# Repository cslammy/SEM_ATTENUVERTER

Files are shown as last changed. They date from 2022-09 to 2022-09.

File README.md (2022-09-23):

# SEM_ATTENUVERTER
Audio Attenuverter inspired by classic Tom Oberheim designs

My First experience with an attenuverter--turn a pot CCW, you get increasing amplitude and a signal in phase; CW and you get increasing amplitude with the signal 180 degrees out of phase, was the filter mod pots found an Oberheim SEM. Was I 14 years old? Well, it blew my young mind....Combined with the SEMs multimode filter you can get all sorts of cool sound with the attenuator/inverter + filter, but now, with attenuverters found everywhere, they are, well, everywhere.  This time I used the same core component that made the SEM attenuverter so cool, the somewhat unusual (but not unobtainium) center tapped pot as module's the centerpiece.  Homage to the mighty TO! At noon you get ground--zilch. Turn the pot and you get attenuverter action.  I also added bias offset for each signal, controllable by CV or a set 5V signal. This is an evolving design....it is for +/- 15V "large format" or Frac, but a +/- 12V Euro redesign in is the works.

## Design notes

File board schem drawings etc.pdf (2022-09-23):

# MAw BOARD

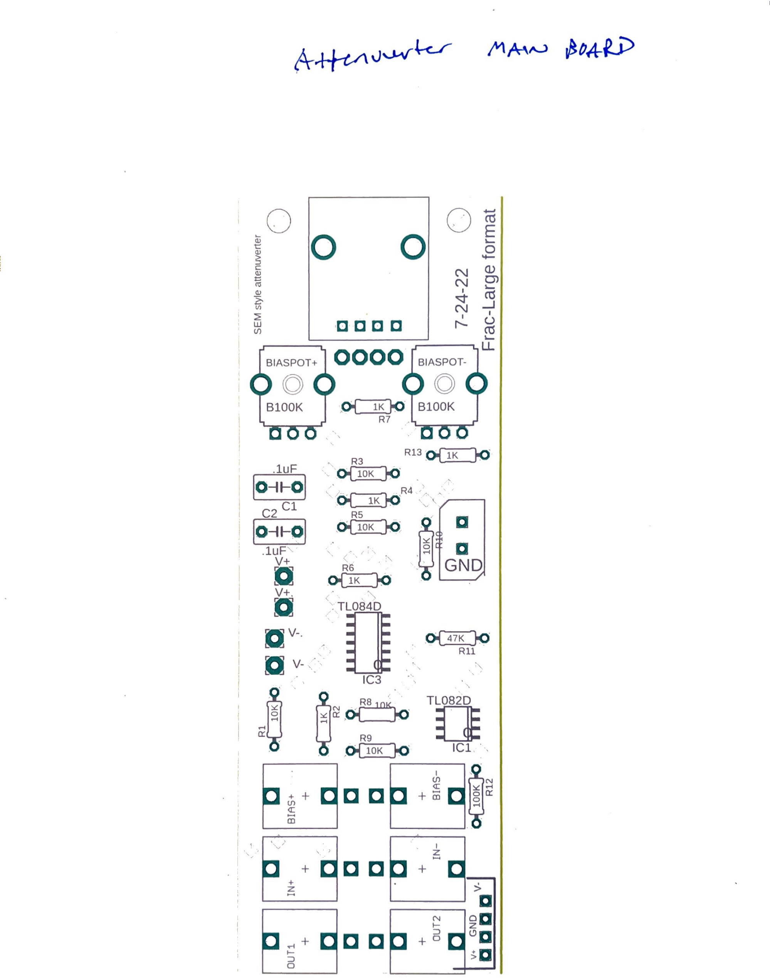
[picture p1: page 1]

3

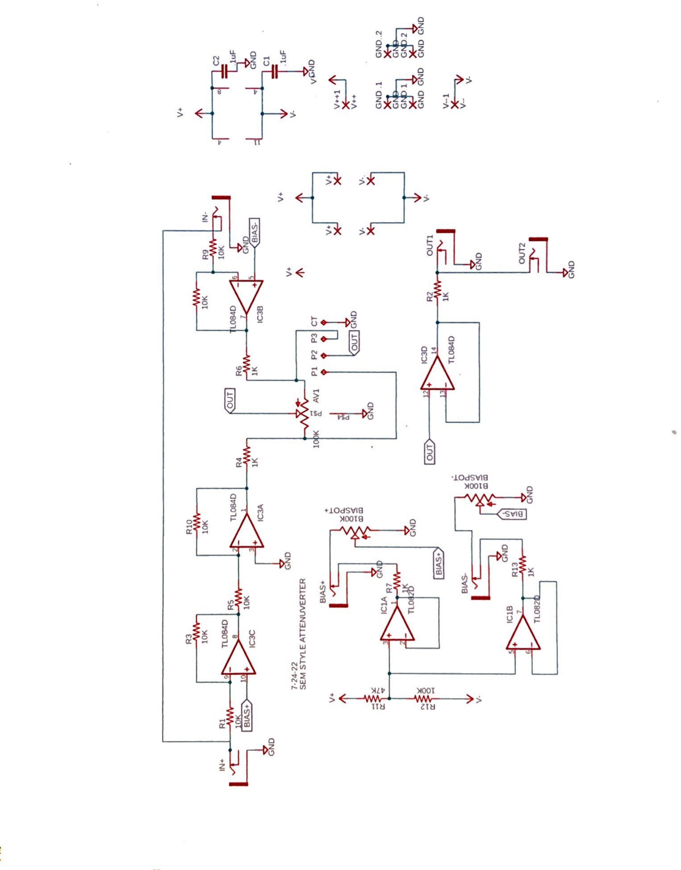
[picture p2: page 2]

f | . | "

?LOdSvIa
OOTE

I-A

ea

v
Tota

Tt

+1LOdsvid
OOTS:

# prerw ete ev pat

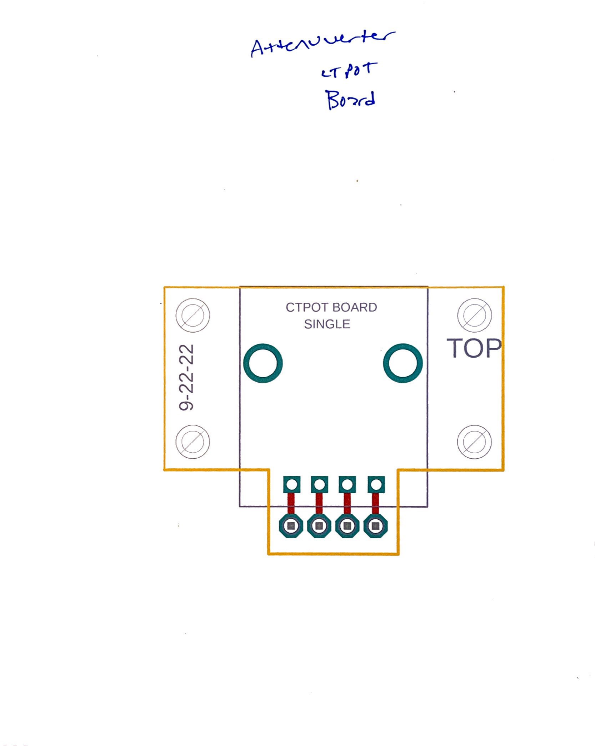
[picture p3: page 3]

# Bord

# CTPOT BOARD SINGLE

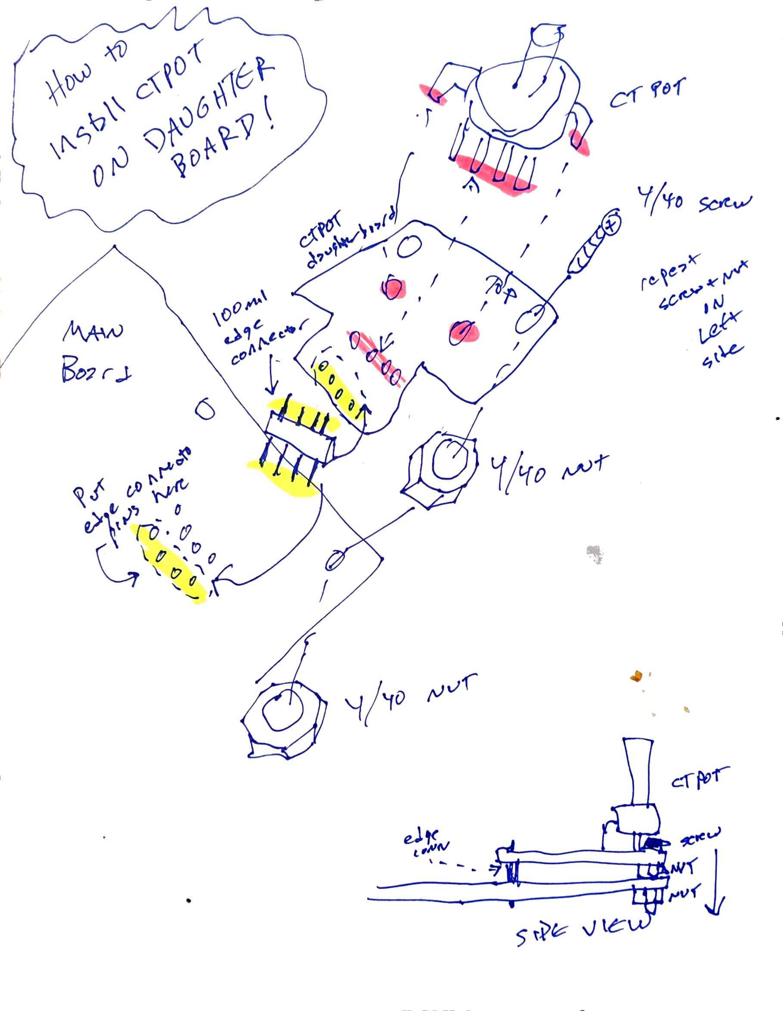
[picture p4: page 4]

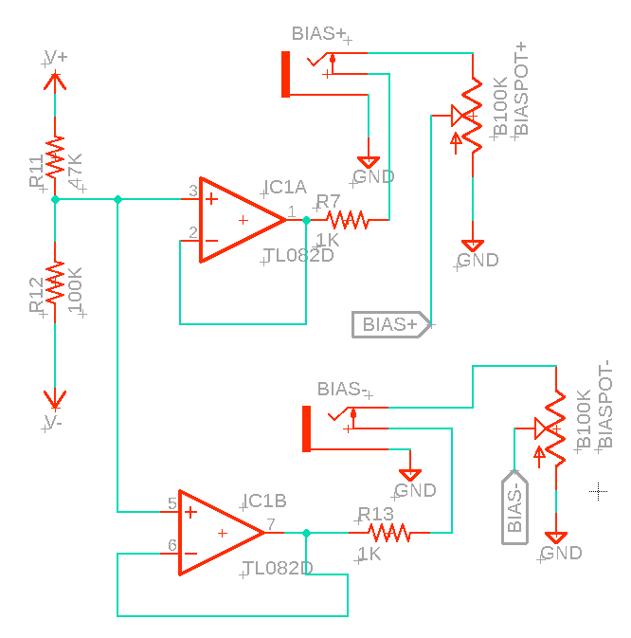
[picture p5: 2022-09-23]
inputaftermod.PNG

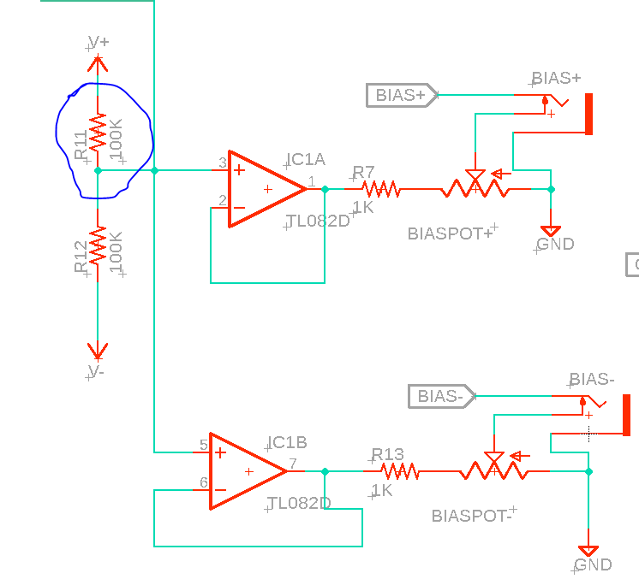
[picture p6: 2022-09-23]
beforebiasinput_mod.PNG

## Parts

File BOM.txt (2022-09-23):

BOM Large Format/Frac SEM style attenuverter

Part     Value         Device           Package         Description                                                                                                
AV1      100K          ALPSRK11K114     ALPSCENTERTAP   ALPS Pot with center tap ground                                                                                                                   
BIAS+    THONKICONNOLD THONKICONNOLD    THONKICONN      3.5mm socket for Eurorack modular synths                                                                                                          
BIAS-    THONKICONNOLD THONKICONNOLD    THONKICONN      3.5mm socket for Eurorack modular synths                                                                                                          
BIASPOT+ B100K         9MM_SNAP-IN_POT_ 9MM_SNAP-IN_POT "Tall Trimmer"  search on thonk.com                                                                                                
BIASPOT- B100K         9MM_SNAP-IN_POT_ 9MM_SNAP-IN_POT "Tall Trimmer"                                                                                                 
C1       .1uF          C5/3.5           C5B3.5          CAPACITOR                                                                                                                                         
C2       .1uF          C5/3.5           C5B3.5          CAPACITOR                                                                                                                                         
                                                                                                                                  
IC1      TL082D        TL082D           SO08            OP AMP                                                                        
IC3      TL084D        TL084D           SO14            OP AMP                                                                                                                                            
IN+      THONKICONNOLD THONKICONNOLD    THONKICONN      3.5mm socket for Eurorack modular synths                                                                                                          
IN-      THONKICONNOLD THONKICONNOLD    THONKICONN      3.5mm socket for Eurorack modular synths                                                                                                          
OUT1     THONKICONNOLD THONKICONNOLD    THONKICONN      3.5mm socket for Eurorack modular synths                                                                                                          
OUT2     THONKICONNOLD THONKICONNOLD    THONKICONN      3.5mm socket for Eurorack modular synths                                                                                                          
P1       TPPAD1-13     TPPAD1-13        P1-13           Test pad NO NAME                                                                                                                                  
P2       TPPAD1-13     TPPAD1-13        P1-13           Test pad NO NAME                                                                                                                                  
P3       TPPAD1-13     TPPAD1-13        P1-13           Test pad NO NAME                                                                                                                                  
R1       10K           R-US_0204/7      0204/7          RESISTOR, American symbol                                                                                                                         
R2       1K            R-US_0204/7      0204/7          RESISTOR, American symbol                                                                                                                         
R3       10K           R-US_0204/7      0204/7          RESISTOR, American symbol                                                                                                                         
R4       1K            R-US_0204/7      0204/7          RESISTOR, American symbol                                                                                                                         
R5       10K           R-US_0204/7      0204/7          RESISTOR, American symbol                                                                                                                         
R6       1K            R-US_0204/7      0204/7          RESISTOR, American symbol                                                                                                                         
R7       1K            R-US_0204/7      0204/7          RESISTOR, American symbol                                                                                                                         
R8       10K           R-US_0204/7      0204/7          RESISTOR, American symbol                                                                                                                         
R9       10K           R-US_0204/7      0204/7          RESISTOR, American symbol                                                                                                                         
R10      10K           R-US_0204/7      0204/7          RESISTOR, American symbol                                                                                                                         
R11      47K           R-US_0204/7      0204/7          RESISTOR, American symbol                                                                                                                         
R12      100K          R-US_0204/7      0204/7          RESISTOR, American symbol                                                                                                                         
R13      1K            R-US_0204/7      0204/7          RESISTOR, American symbol

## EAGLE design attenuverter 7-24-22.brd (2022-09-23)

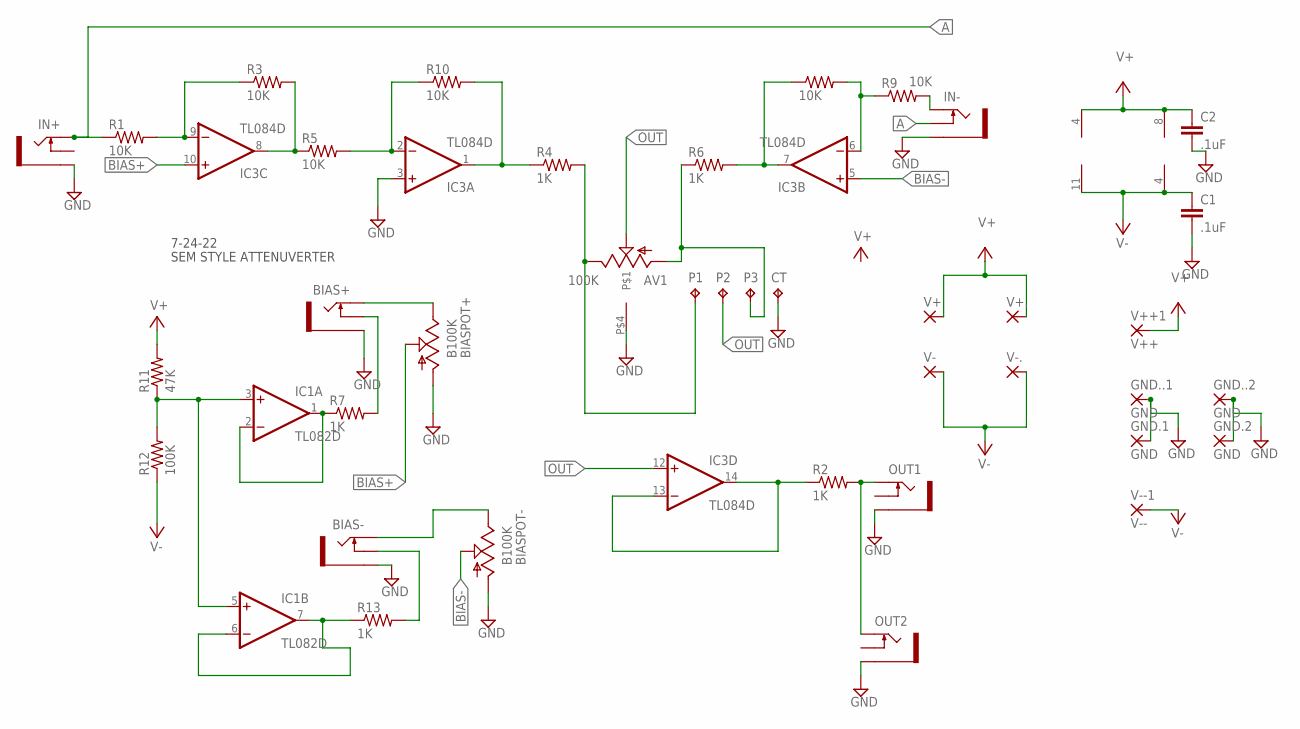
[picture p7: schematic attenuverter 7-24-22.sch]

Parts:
AV1: 100K; ALPSCENTERTAP
BIAS+: THONKICONNOLD; THONKICONN
BIAS-: THONKICONNOLD; THONKICONN
BIASPOT+: B100K; 9MM_SNAP-IN_POT
BIASPOT-: B100K; 9MM_SNAP-IN_POT
C1, C2: .1uF; C5B3.5
CT: TPPAD1-13; P1-13
GND.1, GND.2, GND..1, GND..2: GND; 1,6/0,8
IC1: TL082D; SO08
IC3: TL084D; SO14
IN+: THONKICONNOLD; THONKICONN
IN-: THONKICONNOLD; THONKICONN
OUT1, OUT2: THONKICONNOLD; THONKICONN
P1, P2, P3: TPPAD1-13; P1-13
R1, R3, R5, R8, R9, R10: 10K; 0204/7
R2, R4, R6, R7, R13: 1K; 0204/7
R11: 47K; 0204/7
R12: 100K; 0204/7
V+, V+.: WIREPAD2,54/1,1; 2,54/1,1
V++1: V++; 1,6/0,8
V-, V-.: WIREPAD2,54/1,1; 2,54/1,1
V--1: V--; 1,6/0,8

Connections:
A: IN+.P$3_TIP (TIP), IN-.P$2_SWITCH (SWITCH), R1.1
BIAS+: BIASPOT+.2 (S), IC3.10 (+IN)
BIAS-: BIASPOT-.2 (S), IC3.5 (+IN)
GND: AV1.P$4, BIAS+.P$1_SLEEVE (SLEEVE), BIAS-.P$1_SLEEVE (SLEEVE), BIASPOT+.1 (A), BIASPOT-.1 (A), C1.2, C2.2, CT.TP, GND.1.1, GND.2.1, GND..1.1, GND..2.1, IC3.3 (+IN), IN+.P$1_SLEEVE (SLEEVE), IN-.P$1_SLEEVE (SLEEVE), OUT1.P$1_SLEEVE (SLEEVE), OUT2.P$1_SLEEVE (SLEEVE)
unnamed: IC3.6 (-IN), R8.2, R9.1
unnamed: IC1.3 (+IN), IC1.5 (+IN), R11.1, R12.2
unnamed: IC3.7 (OUT), R6.2, R8.1
unnamed: IC1.1 (OUT), IC1.2 (-IN), R7.1
unnamed: AV1.P$1 (HIGH), P1.TP, R4.2
unnamed: IC1.6 (-IN), IC1.7 (OUT), R13.1
unnamed: BIAS-.P$3_TIP (TIP), BIASPOT-.3 (E)
unnamed: IN-.P$3_TIP (TIP), R9.2
unnamed: BIAS+.P$2_SWITCH (SWITCH), R7.2
unnamed: BIAS-.P$2_SWITCH (SWITCH), R13.2
unnamed: IC3.9 (-IN), R1.2, R3.1
unnamed: IC3.13 (-IN), IC3.14 (OUT), R2.1
unnamed: AV1.P$3 (LOW), P3.TP, R6.1
unnamed: BIAS+.P$3_TIP (TIP), BIASPOT+.3 (E)
unnamed: IC3.8 (OUT), R3.2, R5.1
unnamed: IC3.2 (-IN), R5.2, R10.1
unnamed: IC3.1 (OUT), R4.1, R10.2
unnamed: OUT1.P$3_TIP (TIP), OUT2.P$3_TIP (TIP), R2.2
OUT: AV1.P$2 (WIPER), IC3.12 (+IN), P2.TP
V+: C2.1, IC1.8 (V+), IC3.4 (V+), R11.2, V+.1, V++1.1, V+..1
V-: C1.1, IC1.4 (V-), IC3.11 (V-), R12.1, V-.1, V--1.1, V-..1

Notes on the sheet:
SEM STYLE ATTENUVERTER
7-24-22

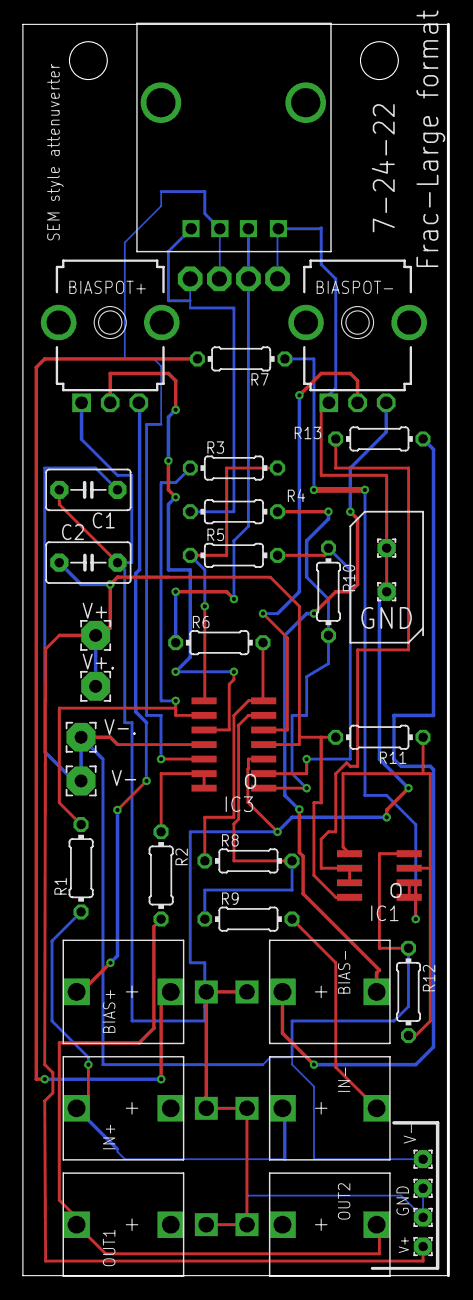
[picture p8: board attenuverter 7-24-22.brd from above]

Board: 2 copper layers, 37.1 x 109.2 mm, 40 parts (0 on the bottom side), 25 nets.

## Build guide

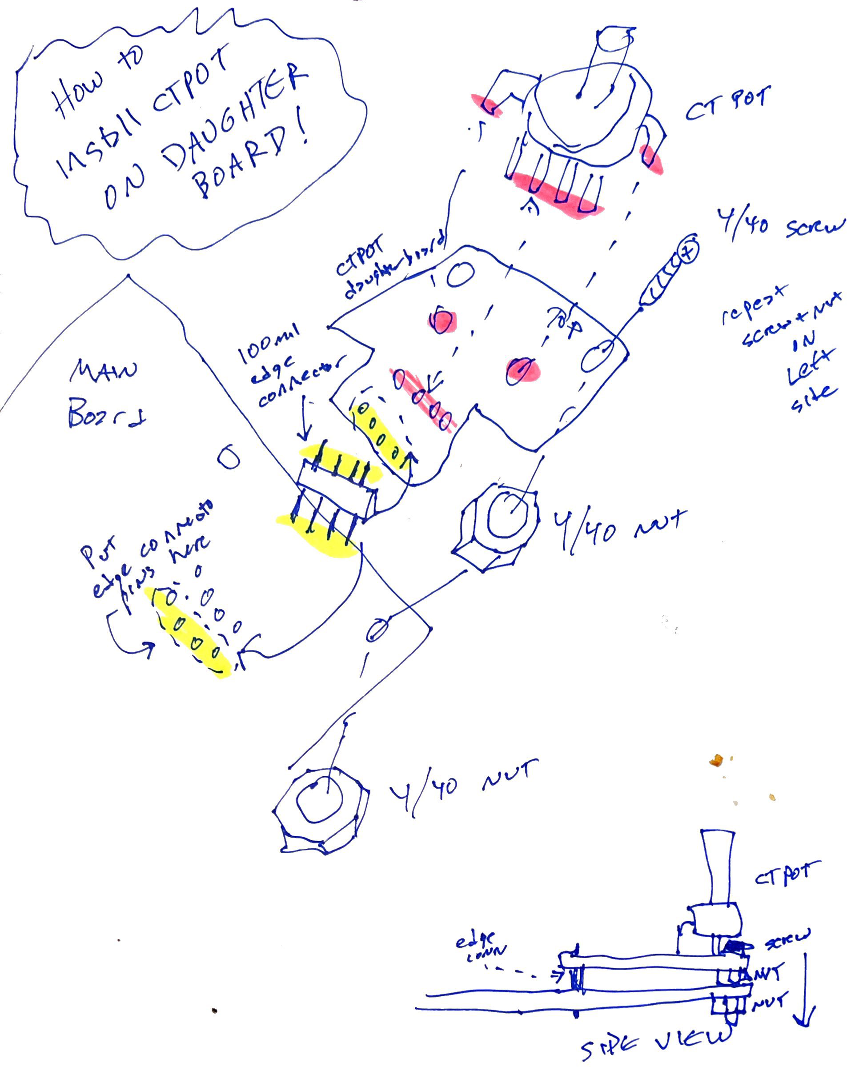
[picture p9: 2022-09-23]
how to install dboard.png
